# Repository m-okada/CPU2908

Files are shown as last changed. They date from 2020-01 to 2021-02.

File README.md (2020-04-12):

CPU2908
====

Open source home brew 8-bit CPU.
----
CPU2908は、74HCシリーズ標準ロジックとROMで作る8ビットCPUです。

FPGAにもインプリメントしてあります。
ターゲットデバイスはLattice MachXO2-1200HC、又は2000HCです。
FPGA版は既にプロトタイプ基版まで出来ているので、不具合を修正してリリース版を作ります。

アーキテクチャ
----
- 8ビットCPU、リトルエンディアン
- 4つの汎用8ビットレジスタ。2つまとめて16ビットレジスタとして使う命令があります
- 4つの16ビットアドレスレジスタ。うち1つはスタックポインタ、1つはプログラムカウンタです
- 命令は全て8ビット長で、後ろにイミディエイト値が1～2バイトつく場合があります
- μCode方式です
- ロード／ストア命令、データ移動命令、算術／論理演算、条件ジャンプ、CALL／RET命令などがあります
- CALL/JUMP命令は8/16ビットオフセット(プログラムカウンタ相対)です

レジスタ構成
----

### 8ビット汎用レジスタR0～R3。

R1とR0は合わせてW0、R3とR2は合わせてW1と表現します。アドレスレジスタとのデータ転送、INC/DEC命令で16ビットレジスタとして使えます。

### 16ビットアドレスレジスタA0、A1、CP、SP。
アドレスレジスタA0、A1はロード/ストア命令でアドレスを指定するのに使います。
また、汎用16ビットレジスタとのデータ転送、交換などの命令もあります。

SPはスタックポインタです。PUSH/POP命令のアドレスはSPが暗黙で指定されます。

CPはコードポインタです。プログラムカウンタ（PC）とかインストラクションポインタ（IP）などの呼び方がありますが、SPがスタックポインタなので、CPがコードポインタです。

μCode方式
----
CPU2908は、主に部品数を減らすためとコード密度を高くするために、μCode（厳密にはコントロールストアと呼ばれる方式）で命令をデコードしています。

回路について
====

回路は
- Logisimのドキュメント CPU2908/Document/CPU2908C3.circ
- KiCadの回路図 CPU2908/blob/master/Schematics/74HC/RevC3/CPU2908C3.sch

の2つで、どちらも同じ回路です。
最初にLogisim用の回路を作り、動作するμCODEを作りました。これでシミュレーションをしながら動作の確認をして、それからKiCadの回路図を起こしました。
MachXO2用のファイルもこの回路図を元に、回路図入力で作ってあります。

詳細は　CPU2908/Document/CPU2908C.ods　にあります。
インストラクションセット、μROM、ピンアウトなど解説してあります。

その他
====
開発の進捗など含めて計算機について色々呟いています。
https://twitter.com/MyCPU8

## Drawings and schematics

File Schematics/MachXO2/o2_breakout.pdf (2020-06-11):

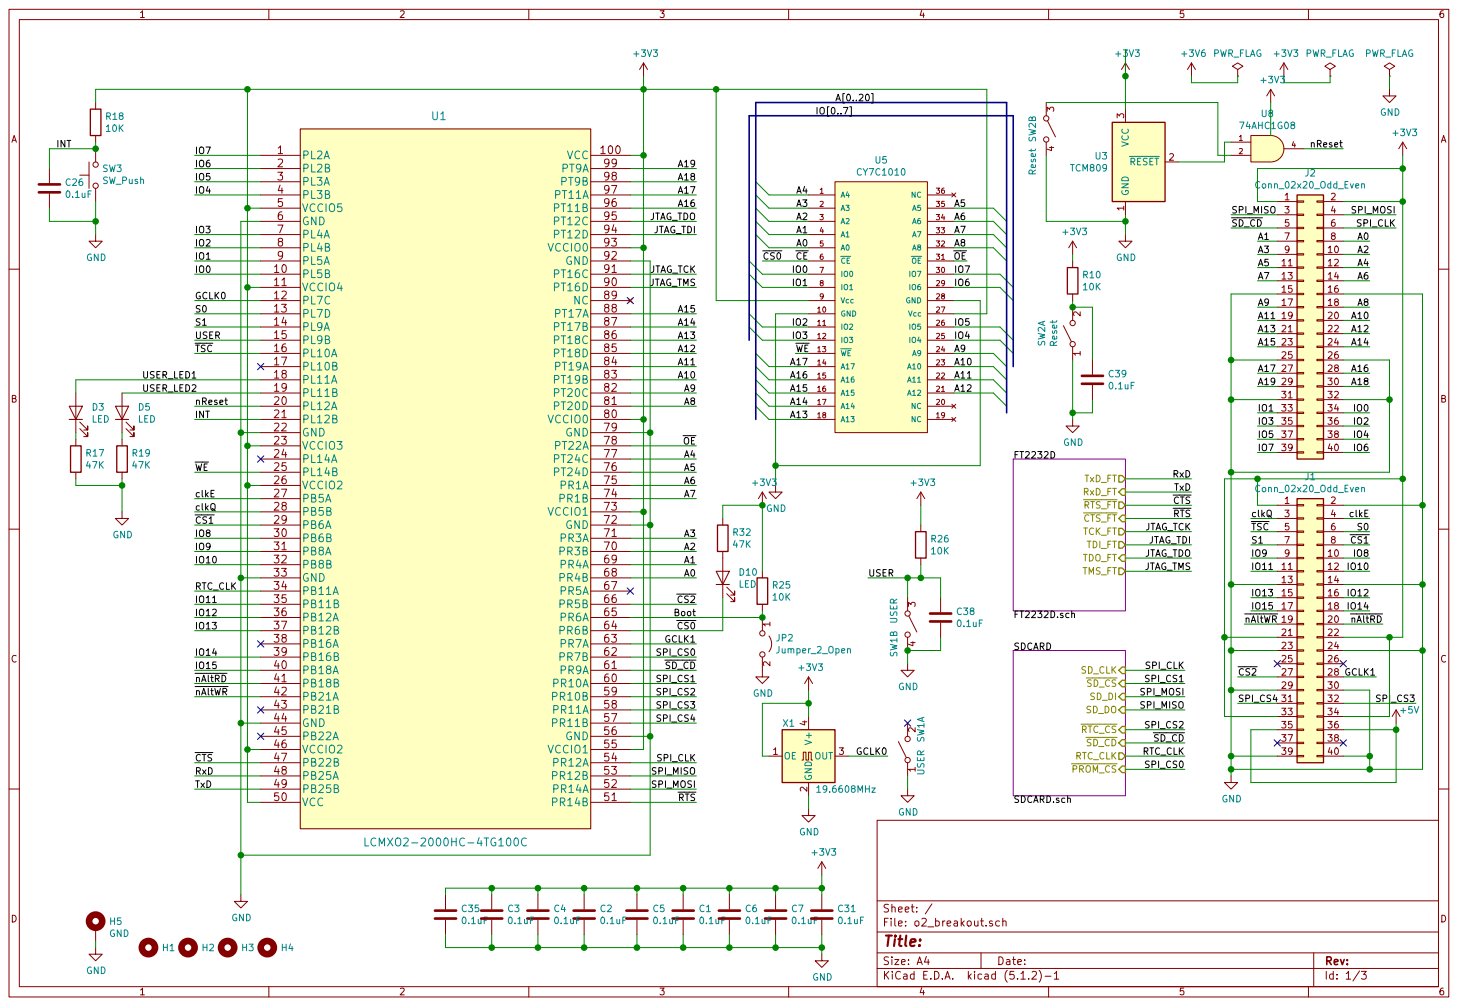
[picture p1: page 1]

17 | SPI_CLK RxD 18

35 | 36
37 39 | 38 40

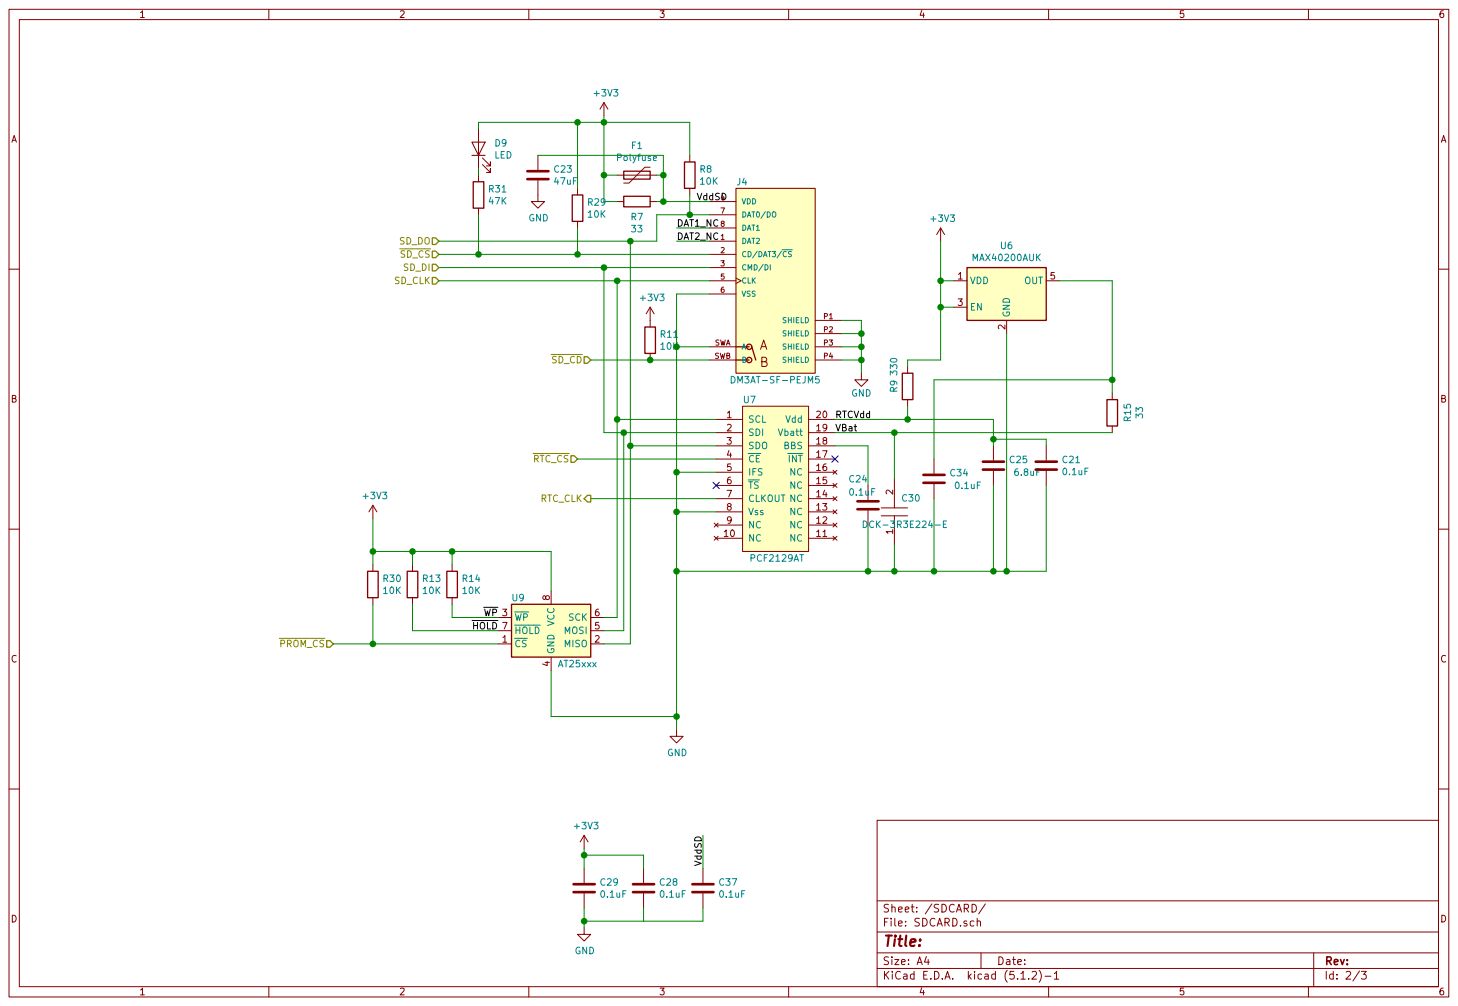
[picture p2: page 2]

Id: 2/3 Title: File: SDCARD.sch Sheet: /SDCARD/ AB

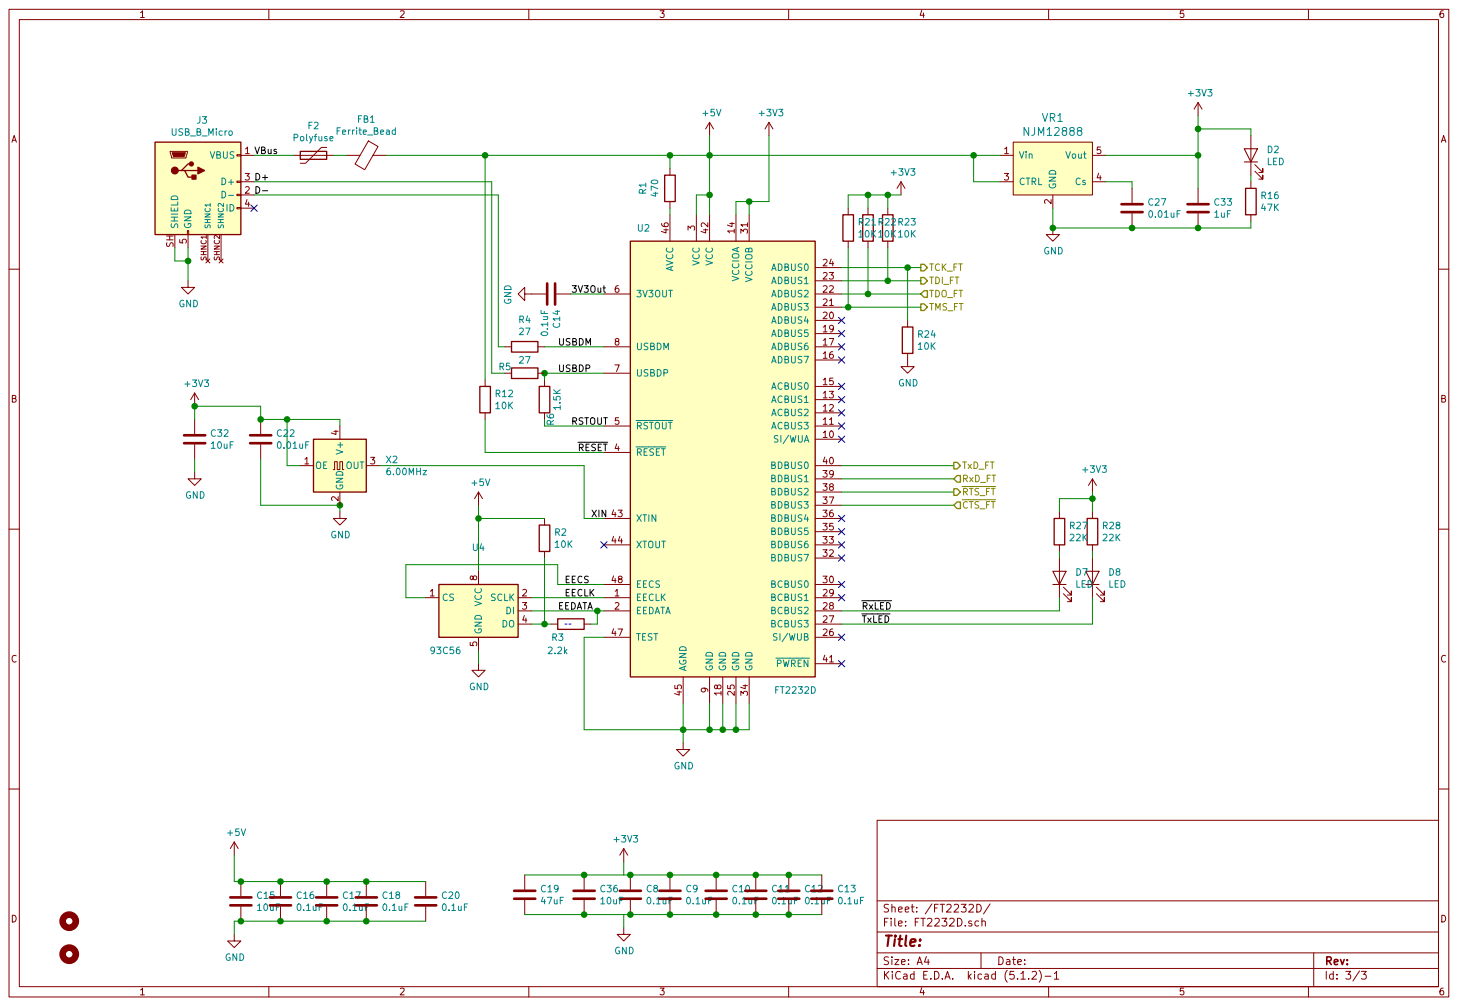
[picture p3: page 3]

2 CTRL 3 Cs 4 Vout 5 VR1 NJM12888 GND GND

3 BCBUS0 30 VCCIOB 31 BDBUS7 32 BDBUS6 33 GND 34 BDBUS5 35 BDBUS4 36 BDBUS3 37 BDBUS2 38 BDBUS1 39 RESET 4 BDBUS0 40 PWREN 41 VCC 42 XTIN 43 XTOUT 44 AGND 45 AVCC 46 TEST 47 EECS 48 RSTOUT 5

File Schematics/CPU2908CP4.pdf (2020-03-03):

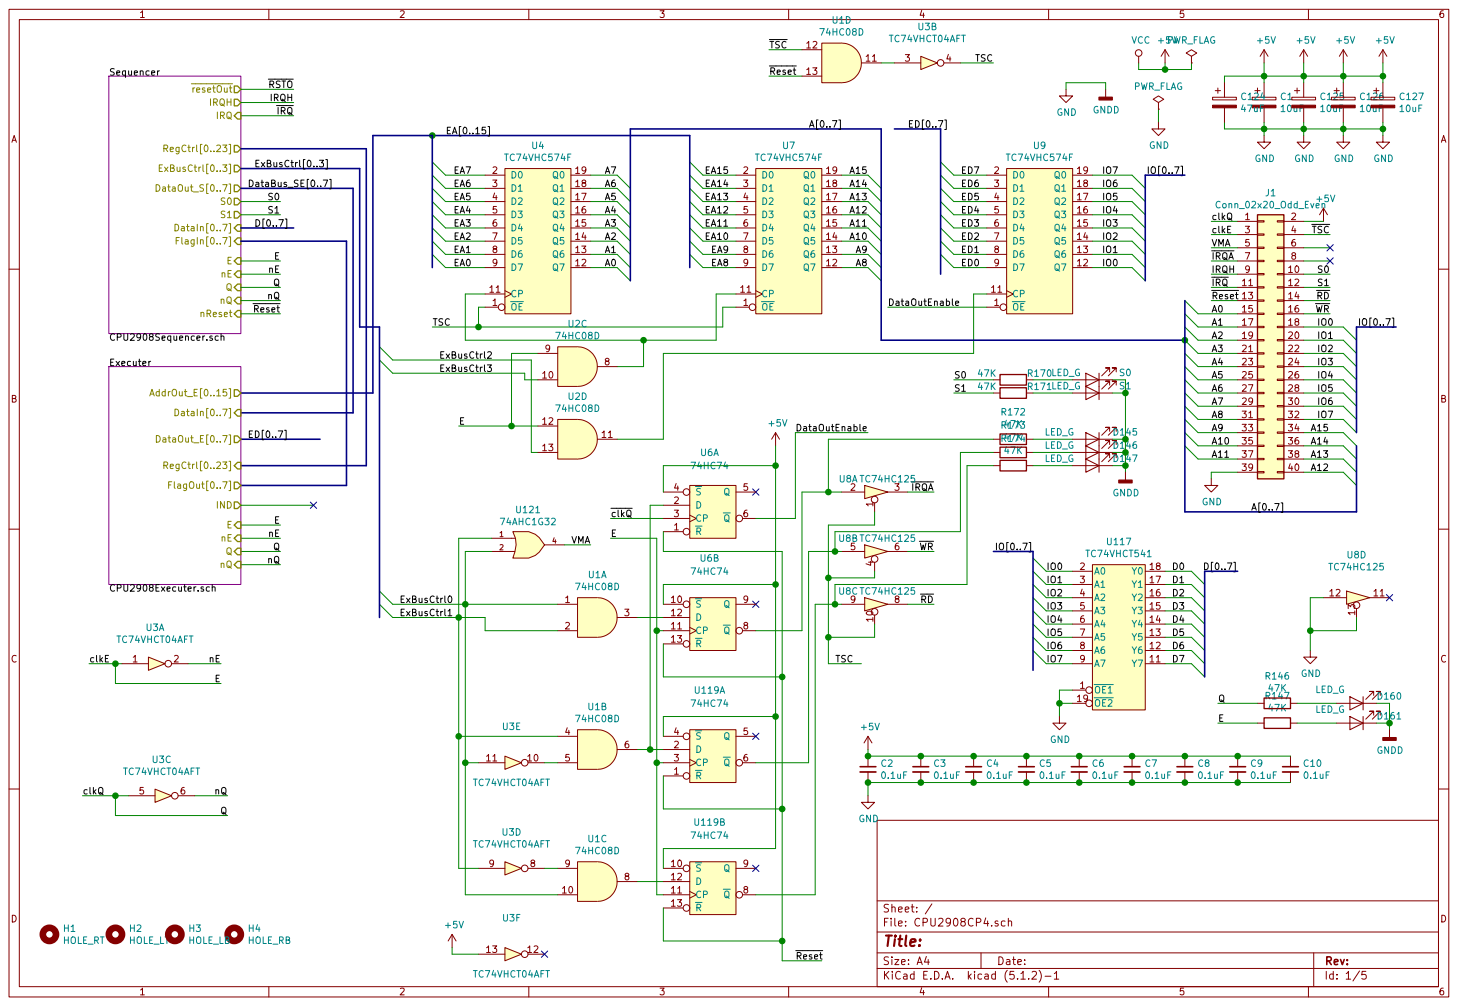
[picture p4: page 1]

Id: 1/5 Title: File: CPU2908CP4.sch Sheet: /

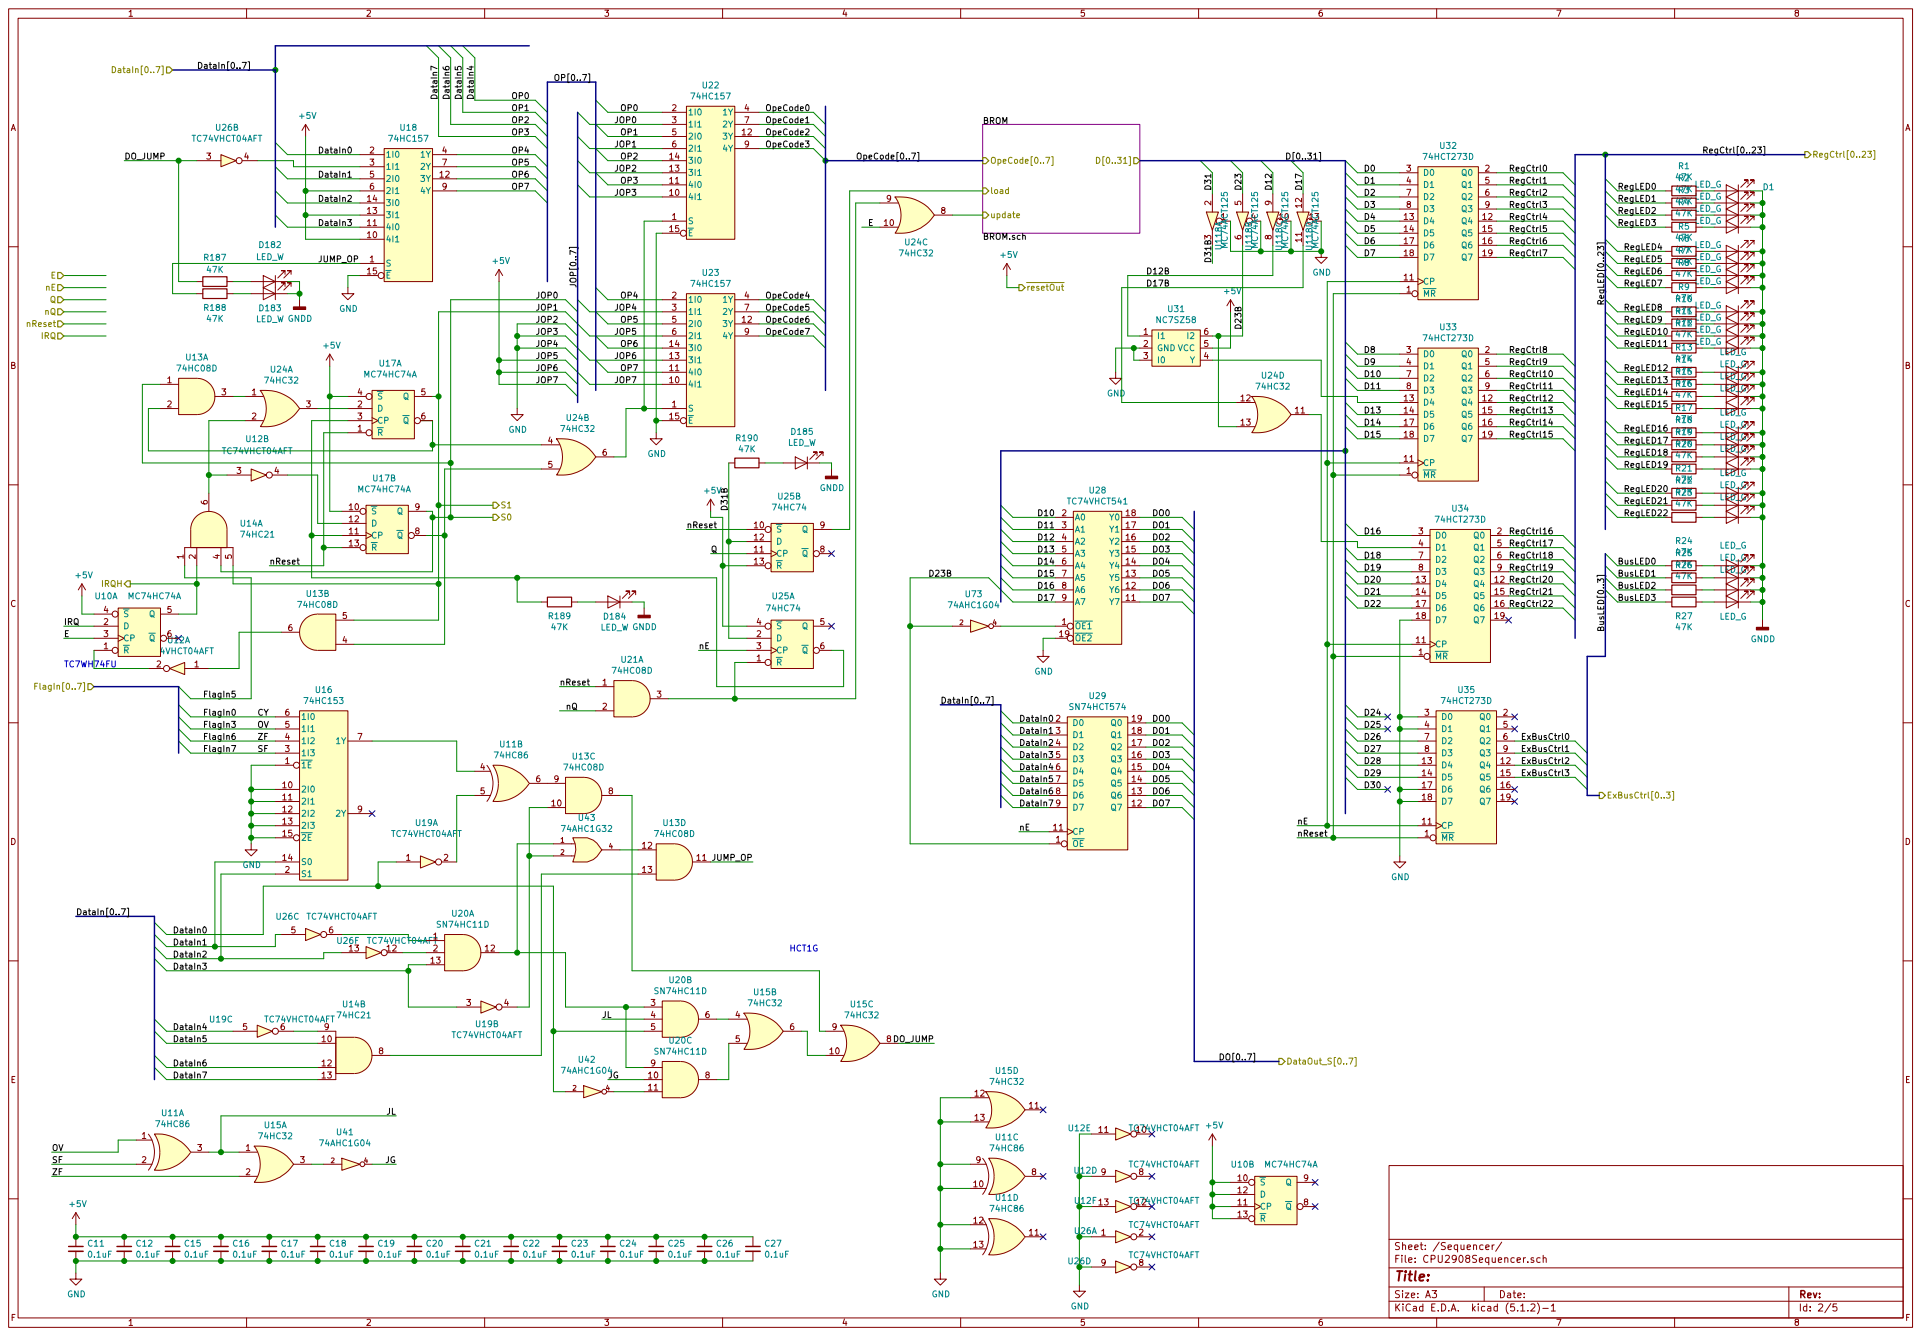
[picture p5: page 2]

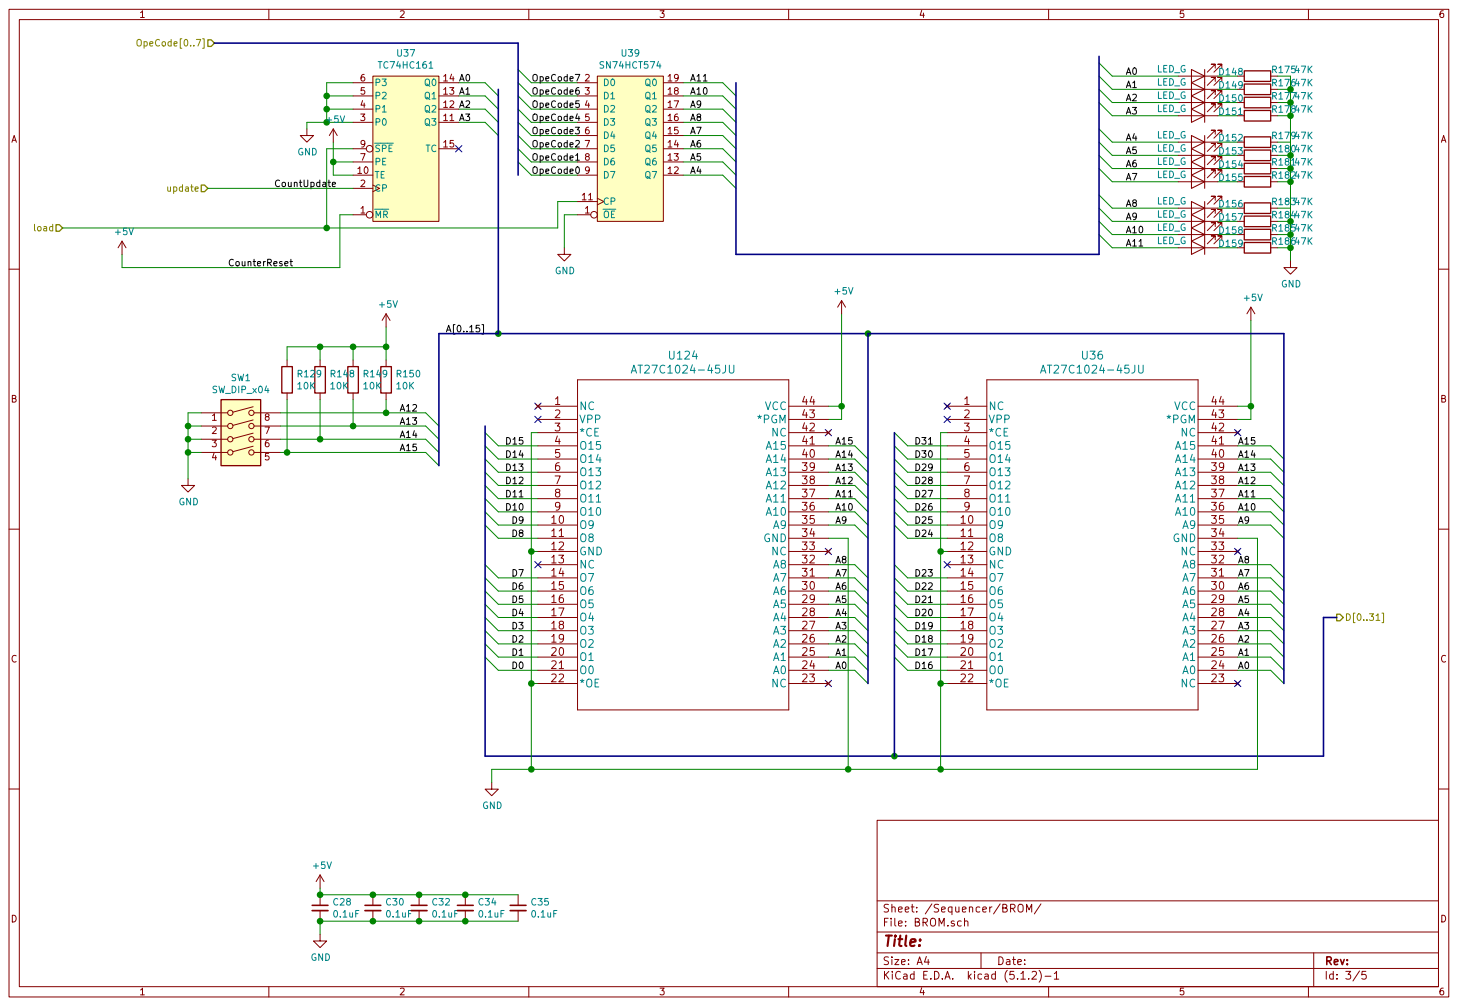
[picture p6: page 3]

Id: 3/5 Title: File: BROM.sch Sheet: /Sequencer/BROM/

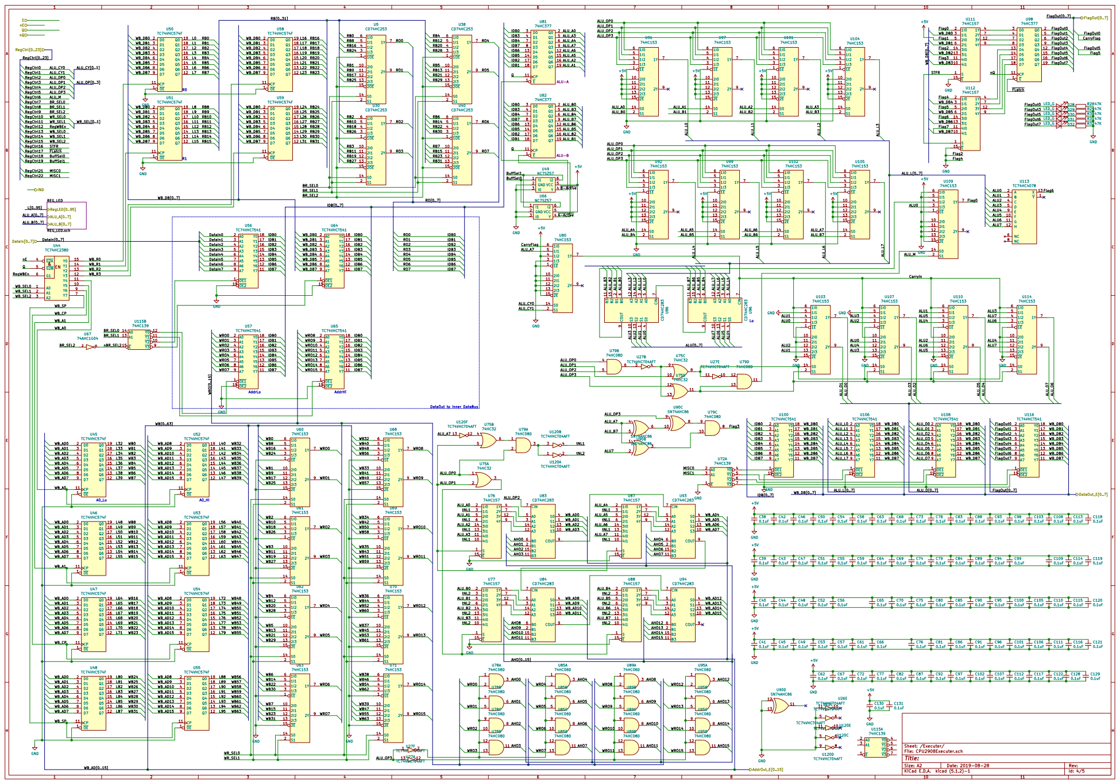
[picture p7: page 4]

TC74VHCT04AFT DataOut to Inner DataBus

Id: 4/5 Title: File: CPU2908Executer.sch Sheet: /Executer/

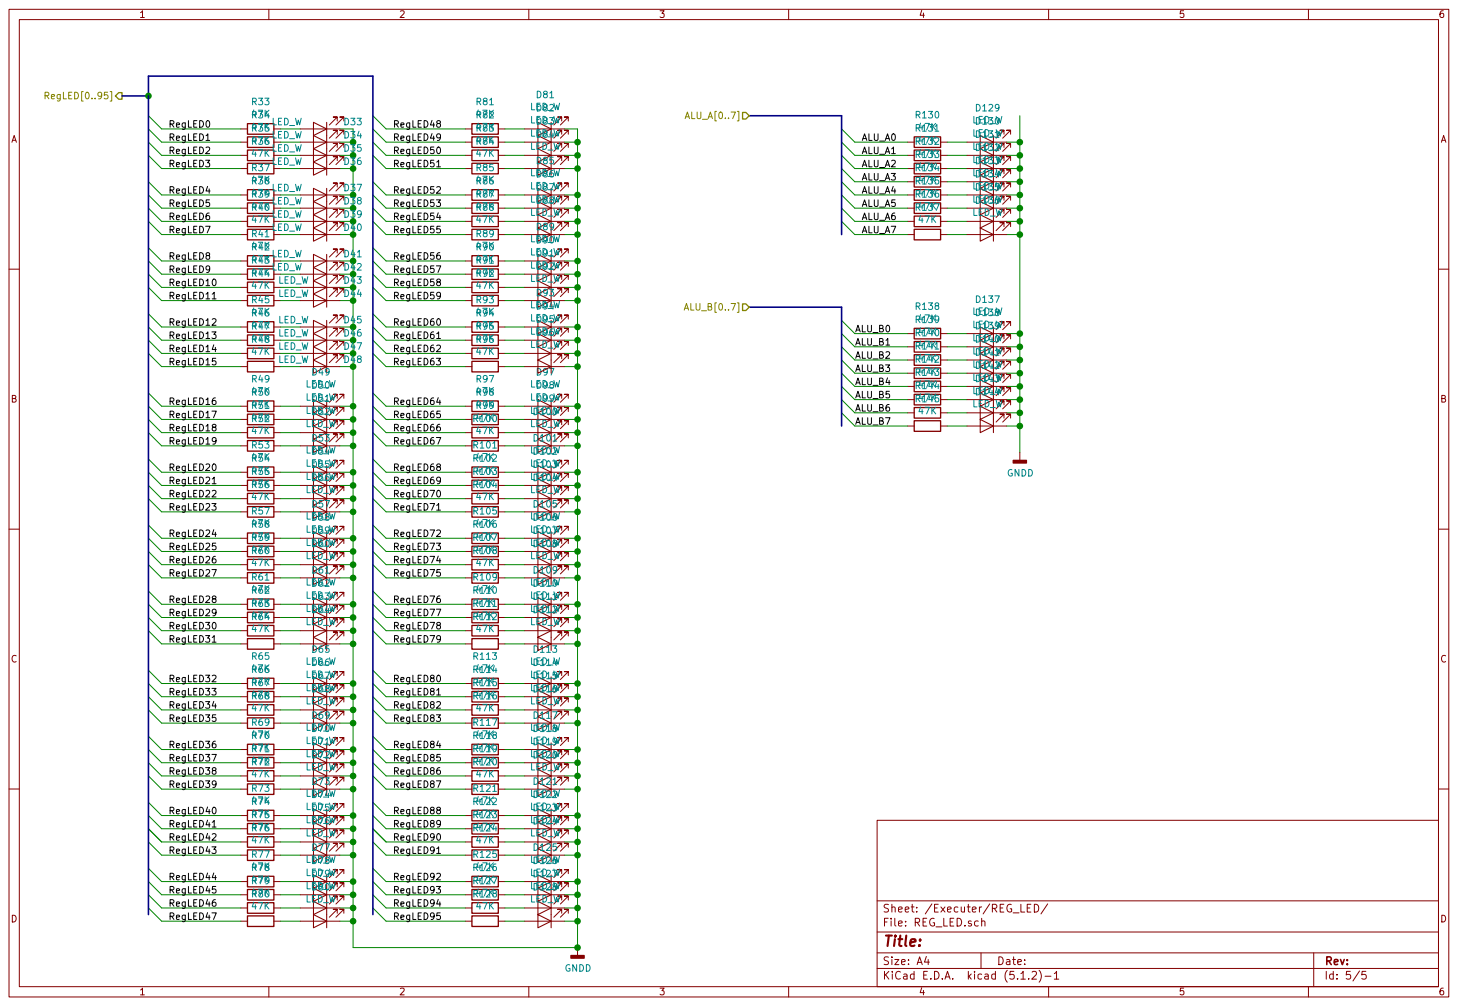
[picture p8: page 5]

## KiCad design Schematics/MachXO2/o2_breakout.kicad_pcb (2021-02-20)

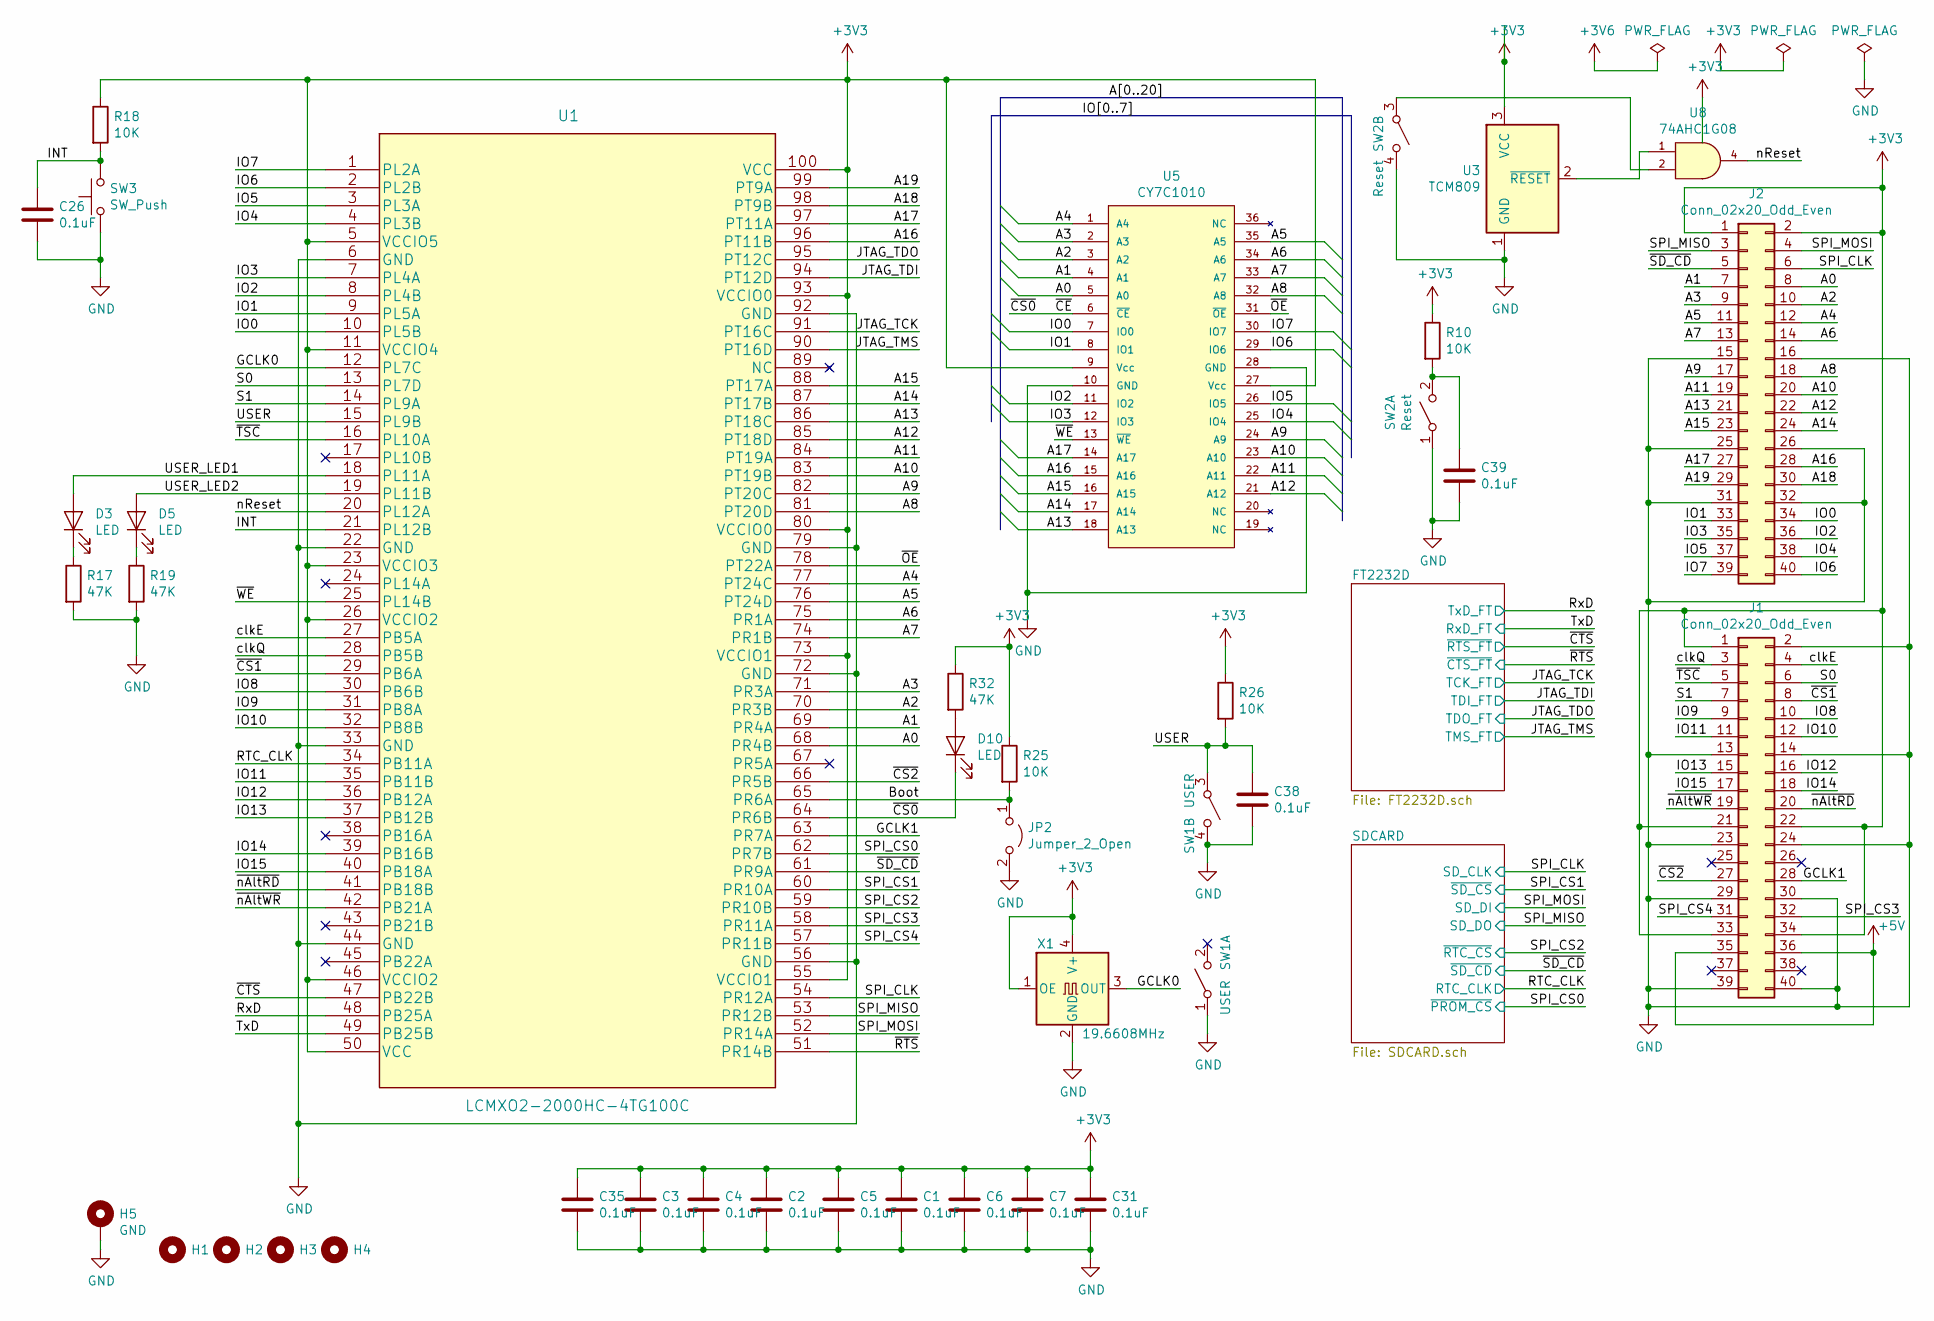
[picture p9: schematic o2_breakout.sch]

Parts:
C1, C2, C3, C4, C5, C6, C7, C26, C31, C35, C38, C39: 0.1uF; C_0402
D3, D5, D10: LED; C_0603
H1, H2, H3, H4: MountingHole; MountingHole_3.2mm_M3
H5: GND; Pin_Header_Straight_1x01_Pitch1.00mm
J1, J2: Conn_02x20_Odd_Even; Pin_Header_Straight_2x20_Pitch2.54mm
JP2: Jumper_2_Open; WireConnection_1.00mmDrill
R10, R18, R25, R26: 10K; C_0402
R17, R19, R32: 47K; C_0402
SW1: USER; SW_PUSH_6mm
SW2: Reset; SW_PUSH_6mm
SW3: SW_Push; SMD-2_3.2x1.5mm
U1: LCMXO2-2000HC-4TG100C; TQFP-100_14x14mm
U3: TCM809; SOT-23-3
U5: CY7C1010; SOJ-36_10.16x23.49mm_P1.27mm
U8: 74AHC1G08; SOT-353_SC-70-5
X1: 19.6608MHz; Oscillator_SMD_EuroQuartz_XO53-4pin_5.0x3.2mm_HandSoldering

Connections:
+3V3: C1.1, C2.1, C3.1, C4.1, C5.1, C6.1, C7.1, C31.1, C35.1, J1.1, J1.21, J1.22, J1.33, J1.34, J2.1, J2.2, R10.1, R18.1, R25.1, R26.1, R32.1, U1.5 (VCCIO5), U1.11 (VCCIO4), U1.23 (VCCIO3), U1.26 (VCCIO2), U1.46 (VCCIO2), U1.50 (VCC), U1.55 (VCCIO1), U1.73 (VCCIO1), U1.80 (VCCIO0), U1.93 (VCCIO0), U1.100 (VCC), U3.3 (VCC), U5.9 (Vcc), U5.27 (Vcc), U8.5 (VCC), X1.1 (OE), X1.4 (V+); also elsewhere on the board
+5V: J1.35, J1.36; also elsewhere on the board
/A0: J2.8, U1.68 (PR4B), U5.5 (A0)
/A1: J2.7, U1.69 (PR4A), U5.4 (A1)
/A2: J2.10, U1.70 (PR3B), U5.3 (A2)
/A3: J2.9, U1.71 (PR3A), U5.2 (A3)
/A4: J2.12, U1.77 (PT24C), U5.1 (A4)
/A5: J2.11, U1.76 (PT24D), U5.35 (A5)
/A6: J2.14, U1.75 (PR1A), U5.34 (A6)
/A7: J2.13, U1.74 (PR1B), U5.33 (A7)
/A8: J2.18, U1.81 (PT20D), U5.32 (A8)
/A9: J2.17, U1.82 (PT20C), U5.24 (A9)
/A10: J2.20, U1.83 (PT19B), U5.23 (A10)
/A11: J2.19, U1.84 (PT19A), U5.22 (A11)
/A12: J2.22, U1.85 (PT18D), U5.21 (A12)
/A13: J2.21, U1.86 (PT18C), U5.18 (A13)
/A14: J2.24, U1.87 (PT17B), U5.17 (A14)
/A15: J2.23, U1.88 (PT17A), U5.16 (A15)
/A16: J2.28, U1.96 (PT11B), U5.15 (A16)
/A17: J2.27, U1.97 (PT11A), U5.14 (A17)
/A18: J2.30, U1.98 (PT9B)
/A19: J2.29, U1.99 (PT9A)
/Boot: JP2.1 (A), R25.2, U1.65 (PR6A)
/GCLK0: U1.12 (PL7C), X1.3 (OUT)
/GCLK1: J1.28, U1.63 (PR7A)
/INT: C26.1, R18.2, SW3.2, U1.21 (PL12B)
/IO0: J2.34, U1.10 (PL5B), U5.7 (IO0)
/IO1: J2.33, U1.9 (PL5A), U5.8 (IO1)
/IO2: J2.36, U1.8 (PL4B), U5.11 (IO2)
/IO3: J2.35, U1.7 (PL4A), U5.12 (IO3)
/IO4: J2.38, U1.4 (PL3B), U5.25 (IO4)
/IO5: J2.37, U1.3 (PL3A), U5.26 (IO5)
/IO6: J2.40, U1.2 (PL2B), U5.29 (IO6)
/IO7: J2.39, U1.1 (PL2A), U5.30 (IO7)
/IO8: J1.10, U1.30 (PB6B)
/IO9: J1.9, U1.31 (PB8A)
/IO10: J1.12, U1.32 (PB8B)
/IO11: J1.11, U1.35 (PB11B)
/IO12: J1.16, U1.36 (PB12A)
/IO13: J1.15, U1.37 (PB12B)
/IO14: J1.18, U1.39 (PB16B)
/IO15: J1.17, U1.40 (PB18A)
/JTAG_TCK: U1.91 (PT16C); also elsewhere on the board
/JTAG_TDI: U1.94 (PT12D); also elsewhere on the board
/JTAG_TDO: U1.95 (PT12C); also elsewhere on the board
/JTAG_TMS: U1.90 (PT16D); also elsewhere on the board
/RTC_CLK: U1.34 (PB11A); also elsewhere on the board
/RxD: U1.48 (PB25A); also elsewhere on the board
/S0: J1.6, U1.13 (PL7D)
/S1: J1.7, U1.14 (PL9A)
/SPI_CLK: J2.6, U1.54 (PR12A); also elsewhere on the board
/SPI_CS0: U1.62 (PR7B); also elsewhere on the board
/SPI_CS1: U1.60 (PR10A); also elsewhere on the board
/SPI_CS2: U1.59 (PR10B); also elsewhere on the board
/SPI_CS3: J1.32, U1.58 (PR11A)
/SPI_CS4: J1.31, U1.57 (PR11B)
/SPI_MISO: J2.3, U1.53 (PR12B); also elsewhere on the board
/SPI_MOSI: J2.4, U1.52 (PR14A); also elsewhere on the board
/TxD: U1.49 (PB25B); also elsewhere on the board
/USER: C38.1, R26.2, SW1.3 (A), U1.15 (PL9B)
/USER_LED1: D3.2 (A), U1.18 (PL11A)
/USER_LED2: D5.2 (A), U1.19 (PL11B)
/clkE: J1.4, U1.27 (PB5A)
/clkQ: J1.3, U1.28 (PB5B)
/nReset: U1.20 (PL12A), U8.4
/~CE: D10.1 (K), U1.64 (PR6B), U5.6 (~CE)
/~CS1: J1.8, U1.29 (PB6A)
/~CS2: J1.27, U1.66 (PR5B)
/~CTS: U1.47 (PB22B); also elsewhere on the board
/~OE: U1.78 (PT22A), U5.31 (~OE)
/~RTS: U1.51 (PR14B); also elsewhere on the board
/~SD_CD: J2.5, U1.61 (PR9A); also elsewhere on the board
/~TSC: J1.5, U1.16 (PL10A)
/~WE: U1.25 (PL14B), U5.13 (~WE)
/~nAltRD: J1.20, U1.41 (PB18B)
/~nAltWR: J1.19, U1.42 (PB21A)
GND: C1.2, C2.2, C3.2, C4.2, C5.2, C6.2, C7.2, C26.2, C31.2, C35.2, C38.2, C39.2, H5.1, J1.2, J1.13, J1.14, J1.23, J1.24, J1.29, J1.30, J1.39, J1.40, J2.15, J2.16, J2.25, J2.26, J2.31, J2.32, JP2.2 (B), R17.2, R19.2, SW1.1 (A), SW1.4 (B), SW2.1 (A), SW2.4 (B), SW3.1, U1.6 (GND), U1.22 (GND), U1.33 (GND), U1.44 (GND), U1.56 (GND), U1.72 (GND), U1.79 (GND), U1.92 (GND), U3.1 (GND), U5.10 (GND), U5.28 (GND), U8.3 (GND), X1.2 (GND); also elsewhere on the board
unnamed: C39.1, R10.2, SW2.2 (B)
unnamed: D3.1 (K), R17.1
unnamed: D5.1 (K), R19.1
unnamed: D10.2 (A), R32.2
unnamed: SW2.3 (A), U8.2
unnamed: U3.2 (~RESET~), U8.1

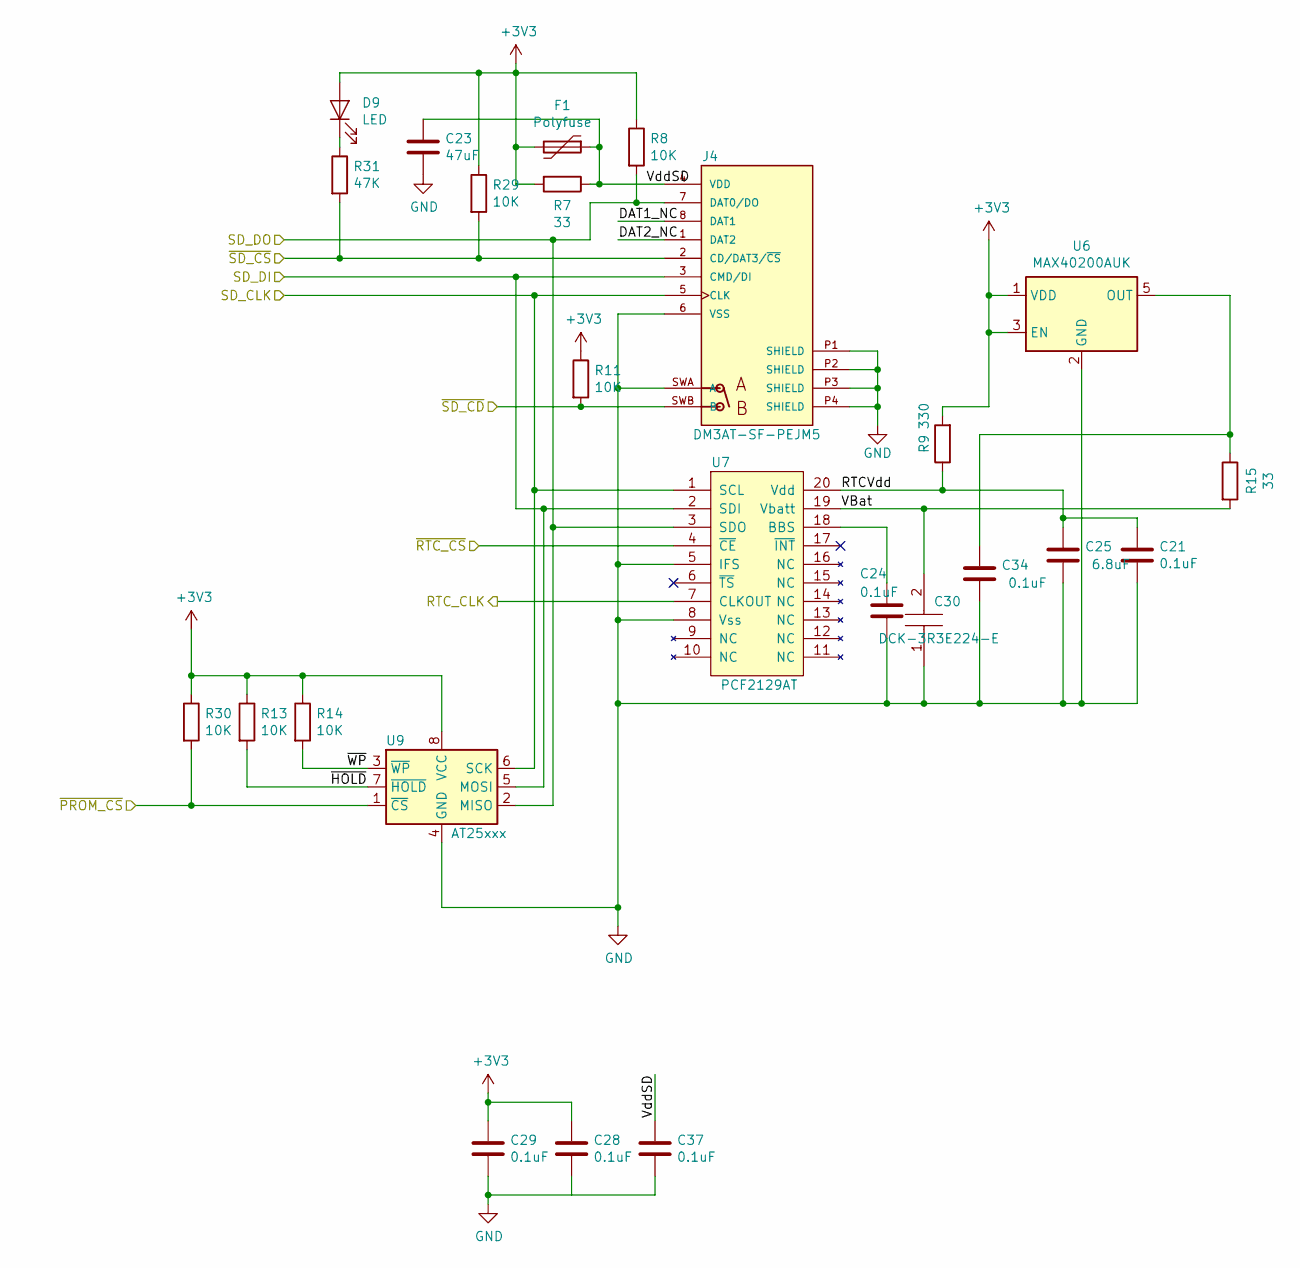
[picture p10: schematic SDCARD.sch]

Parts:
C21, C24, C28, C29, C34, C37: 0.1uF; C_0402
C23: 47uF; C_1210
C25: 6.8uF; C_0805
C30: DCK-3R3E224-E; Manufacturer_Part_Number DCK-3R3E224-E
D9: LED; C_0603
F1: Polyfuse; C_0805
J4: DM3AT-SF-PEJM5; HRS_DM3AT-SF-PEJM5
R7: 33; C_0805
R8, R11, R13, R14, R29, R30: 10K; C_0402
R9: 330; C_0603
R15: 33; C_0603
R31: 47K; C_0402
U6: MAX40200AUK; SOT-23-5
U7: PCF2129AT; SOIC-20W_7.5x12.8mm_Pitch1.27mm
U9: AT25xxx; SOIC-8_3.9x4.9mm_Pitch1.27mm

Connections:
+3V3: C28.1, C29.1, D9.2 (A), F1.2, R7.2, R8.1, R9.2, R11.1, R13.1, R14.1, R29.1, R30.1, U6.1 (VDD), U6.3 (EN), U9.8 (VCC); also elsewhere on the board
/RTC_CLK: U7.7 (CLKOUT); also elsewhere on the board
/SDCARD/DAT1_NC: J4.8 (DAT1)
/SDCARD/DAT2_NC: J4.1 (DAT2)
/SDCARD/RTCVdd: C21.1, C25.1, R9.1, U7.20 (Vdd)
/SDCARD/VBat: C30.2, R15.2, U7.19 (Vbatt)
/SDCARD/VddSD: C23.1, C37.1, F1.1, J4.4 (VDD), R7.1
/SDCARD/~HOLD: R13.2, U9.7 (~HOLD)
/SDCARD/~WP: R14.2, U9.3 (~WP)
/SPI_CLK: J4.5 (CLK), U7.1 (SCL), U9.6 (SCK); also elsewhere on the board
/SPI_CS0: R30.2, U9.1 (~CS); also elsewhere on the board
/SPI_CS1: J4.2 (CD/DAT3/~CS), R29.2, R31.2; also elsewhere on the board
/SPI_CS2: U7.4 (~CE); also elsewhere on the board
/SPI_MISO: J4.7 (DAT0/DO), R8.2, U7.3 (SDO), U9.2 (MISO); also elsewhere on the board
/SPI_MOSI: J4.3 (CMD/DI), U7.2 (SDI), U9.5 (MOSI); also elsewhere on the board
/~SD_CD: J4.SWB (B), R11.2; also elsewhere on the board
GND: C21.2, C23.2, C24.2, C25.2, C28.2, C29.2, C30.1, C34.2, C37.2, J4.6 (VSS), J4.P1 (SHIELD), J4.P2 (SHIELD), J4.P3 (SHIELD), J4.P4 (SHIELD), J4.SWA (A), U6.2 (GND), U7.5 (IFS), U7.8 (Vss), U9.4 (GND); also elsewhere on the board
unnamed: C24.1, U7.18 (BBS)
unnamed: C34.1, R15.1, U6.5 (OUT)
unnamed: D9.1 (K), R31.1

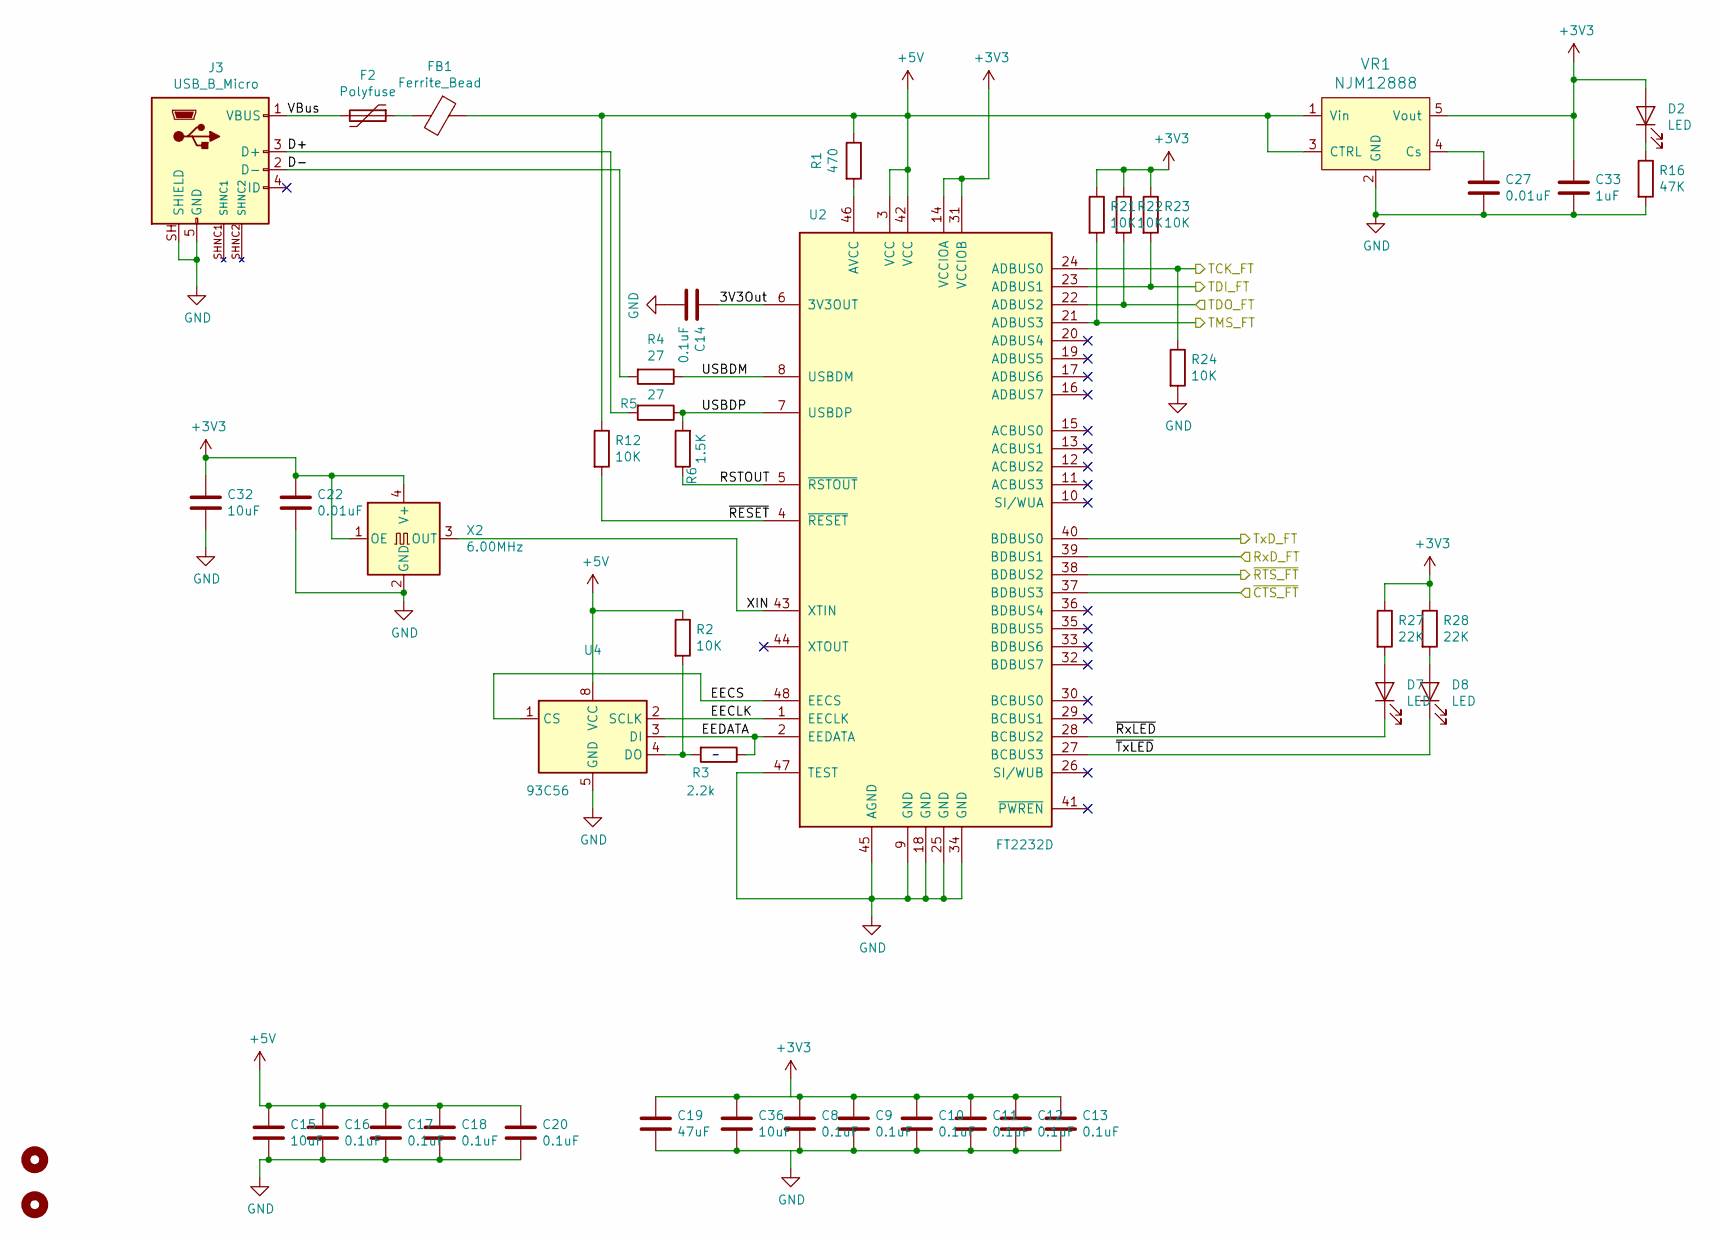
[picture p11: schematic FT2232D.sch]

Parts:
C8, C9, C10, C11, C12, C13, C14, C16, C17, C18, C20: 0.1uF; C_0402
C15, C36: 10uF; C_0603
C19: 47uF; C_0805_HandSoldering
C22: 0.01uF; C_0402
C27: 0.01uF; C_0603
C32: 10uF; C_0805_HandSoldering
C33: 1uF; C_0603
D2: LED; C_0603
D7, D8: LED; C_0402
F2: Polyfuse; C_0805
FB1: Ferrite_Bead; C_0805
H6, H7: MountingHole; MountingHole_1.2mm
J3: USB_B_Micro; HRS_ZX62R-B-5P
R1: 470; C_0603
R2: 10K; C_0603
R3: 2.2k; C_0603
R4, R5: 27; C_0603
R6: 1.5K; C_0603
R12, R21, R22, R23, R24: 10K; C_0402
R16: 47K; C_0603
R27, R28: 22K; C_0402
U2: FT2232D; TQFP-48_7x7mm
U4: 93C56; SOIC-8_3.9x4.9mm_Pitch1.27mm
VR1: NJM12888; SOT-23-5
X2: 6.00MHz; Oscillator_SMD_SeikoEpson_SG8002LB-4pin_5.0x3.2mm_HandSolde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

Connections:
+3V3: C8.1, C9.1, C10.1, C11.1, C12.1, C13.1, C19.1, C22.1, C32.1, C33.1, C36.1, D2.2 (A), R21.1, R22.1, R23.1, R27.1, R28.1, U2.14 (VCCIOA), U2.31 (VCCIOB), VR1.5 (Vout), X2.1 (OE), X2.4 (V+); also elsewhere on the board
+5V: C15.1, C16.1, C17.1, C18.1, C20.1, FB1.1, R1.1, R2.1, R12.1, U2.3 (VCC), U2.42 (VCC), U4.8 (VCC), VR1.1 (Vin), VR1.3 (CTRL); also elsewhere on the board
/FT2232D/3V3Out: C14.1, U2.6 (3V3OUT)
/FT2232D/D+: J3.3 (D+), R5.2
/FT2232D/D-: J3.2 (D-), R4.2
/FT2232D/EECLK: U2.1 (EECLK), U4.2 (SCLK)
/FT2232D/EECS: U2.48 (EECS), U4.1 (CS)
/FT2232D/EEDATA: R3.1, U2.2 (EEDATA), U4.3 (DI)
/FT2232D/RSTOUT: R6.1, U2.5 (~RSTOUT)
/FT2232D/USBDM: R4.1, U2.8 (USBDM)
/FT2232D/USBDP: R5.1, R6.2, U2.7 (USBDP)
/FT2232D/VBus: F2.2, J3.1 (VBUS)
/FT2232D/XIN: U2.43 (XTIN), X2.3 (OUT)
/FT2232D/~RESET: R12.2, U2.4 (~RESET)
/FT2232D/~RxLED: D7.1 (K), U2.28 (BCBUS2)
/FT2232D/~TxLED: D8.1 (K), U2.27 (BCBUS3)
/JTAG_TCK: R24.1, U2.24 (ADBUS0); also elsewhere on the board
/JTAG_TDI: R23.2, U2.23 (ADBUS1); also elsewhere on the board
/JTAG_TDO: R22.2, U2.22 (ADBUS2); also elsewhere on the board
/JTAG_TMS: R21.2, U2.21 (ADBUS3); also elsewhere on the board
/RxD: U2.40 (BDBUS0); also elsewhere on the board
/TxD: U2.39 (BDBUS1); also elsewhere on the board
/~CTS: U2.38 (BDBUS2); also elsewhere on the board
/~RTS: U2.37 (BDBUS3); also elsewhere on the board
GND: C8.2, C9.2, C10.2, C11.2, C12.2, C13.2, C14.2, C15.2, C16.2, C17.2, C18.2, C19.2, C20.2, C22.2, C27.2, C32.2, C33.2, C36.2, J3.5 (GND), J3.SH (SHIELD), R16.2, R24.2, U2.9 (GND), U2.18 (GND), U2.25 (GND), U2.34 (GND), U2.45 (AGND), U2.47 (TEST), U4.5 (GND), VR1.2 (GND), X2.2 (GND); also elsewhere on the board
unnamed: C27.1, VR1.4 (Cs)
unnamed: D2.1 (K), R16.1
unnamed: D7.2 (A), R27.2
unnamed: D8.2 (A), R28.2
unnamed: F2.1, FB1.2
unnamed: R1.2, U2.46 (AVCC)
unnamed: R2.2, R3.2, U4.4 (DO)

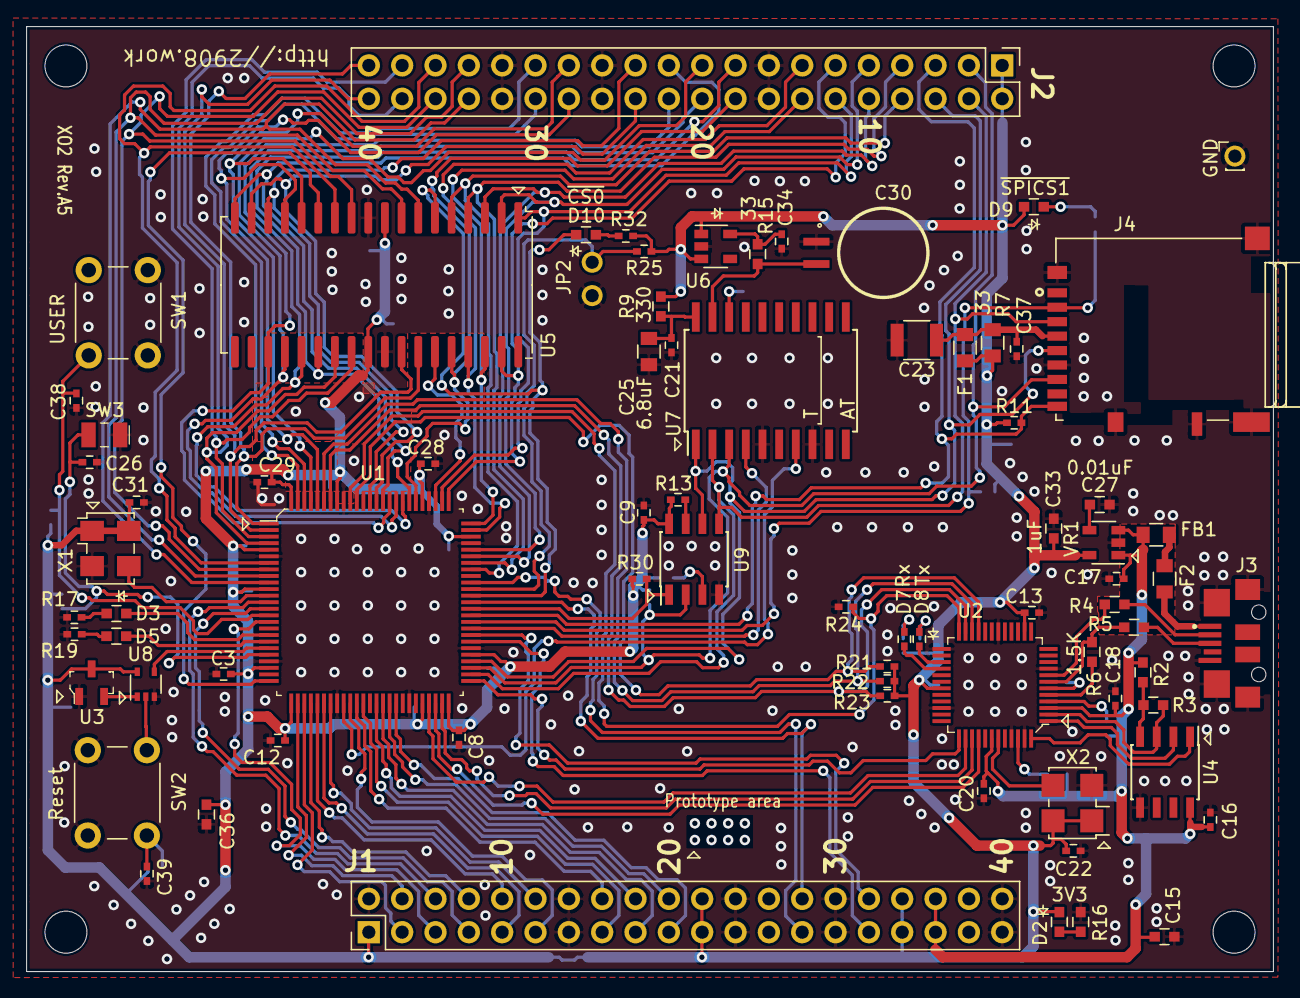
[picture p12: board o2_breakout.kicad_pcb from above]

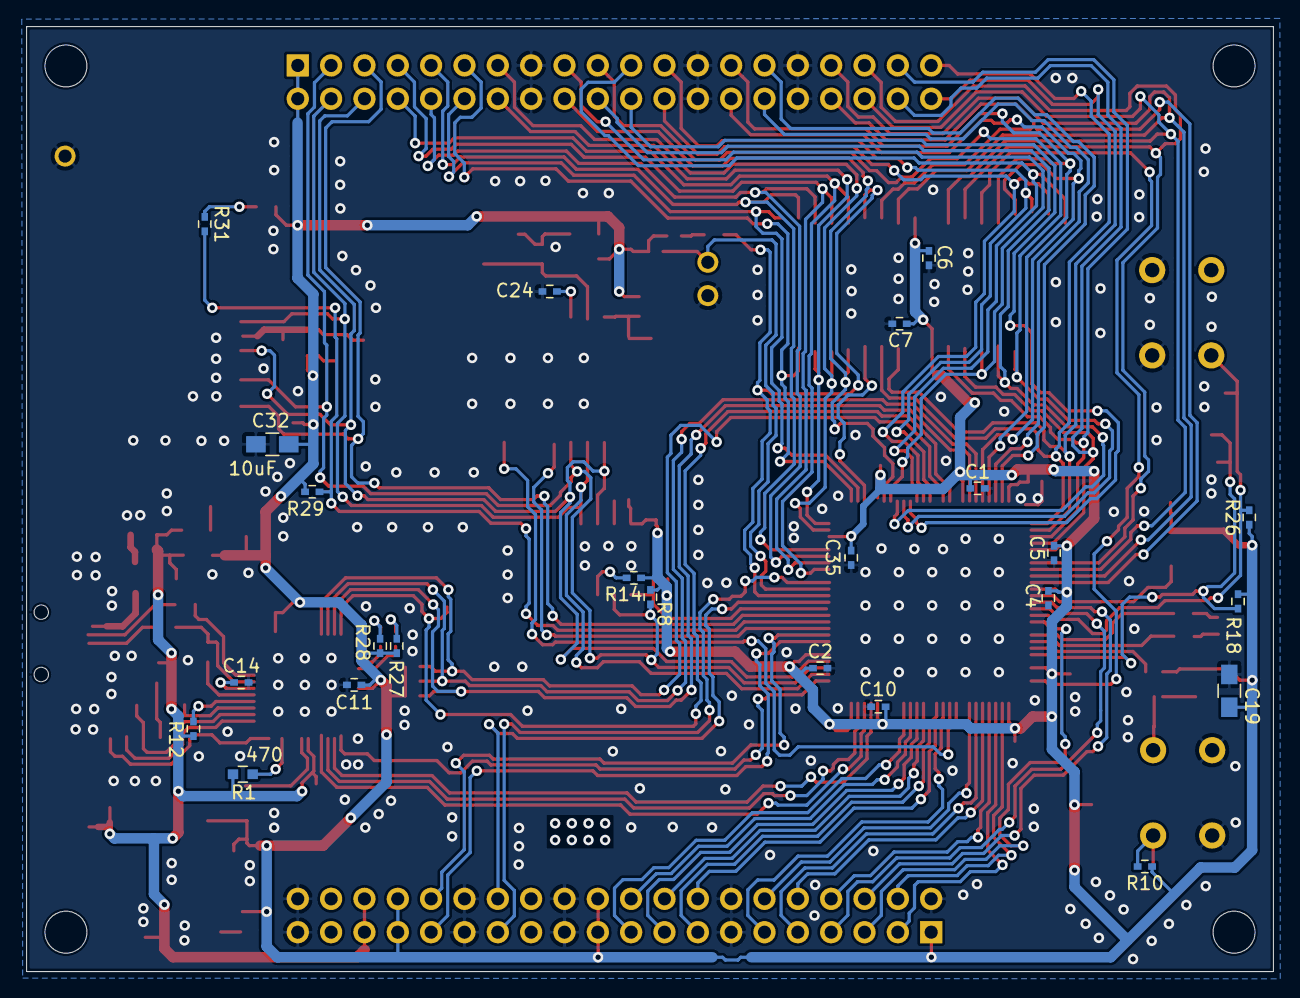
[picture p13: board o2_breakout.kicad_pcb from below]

Board: 2 copper layers, 95.0 x 72.0 mm, 107 parts (24 on the bottom side), 112 nets.

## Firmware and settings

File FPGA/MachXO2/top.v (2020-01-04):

module top(
	inout wire [7:0] dataBus,
	output wire [3:0] nCS,		// chip select 0:ROM 1:RAM 2..:I/O
	input wire clk,
	input wire gclk1,

	input wire nReset,
	input wire nIRQ,
	input wire nTSC,
	
	input wire bootMode,
	
	output wire [19:0] addrOut,
	output wire clkQ,
	output wire clkE,

	output wire nRD,nAltRD,
	output wire nWR,nAltWR,
	output wire nIRQA,
	output wire IRQH,
	
	output wire [1:0]S,
	

	output wire SPI_CLK,
	output wire SPI_MISO,
	output wire SPI_MOSI,
	output wire [5:0]SPI_CS,

	output wire TxD,
	input wire RxD,
	output wire nRTS,
	input wire nCTS,
	output wire SerialClock,

	input wire [3:0]monitor_sel,
	output wire [7:0]UM
);
//wire [3:0]monitor_sel ;
wire [127:0]sig ;


wire [7:0]ExDataIn ;
wire [7:0]ExDataOut ;

wire [15:0]addr ;
wire [3:0] addrHi ;

//wire nwr_temp ;

assign addrOut[15:0] = addr ;
assign addrOut[19:16] = nTSC==1'b1 ? addrHi : 4'bz ;
assign dataBus = nWR==1'b0 ? ExDataOut : 8'bz ;

assign nAltRD = nRD ;
assign nAltWR = nWR ;

//	clock
wire SerialClock2 ;

wire iclk ;	//	Internal clock.
wire clk3 ;	//	clock enable
wire nReset1 ;
wire nReset2 ;
wire main_clk ;

// assign main_clk=gclk1 ;
 assign main_clk=clk ;

assign iclk = clk3 & main_clk ;

assign serlal_clk=clk ;

wire dclk ;

// divider2 div2(.clockIn(iclk),.nReset(nReset2),.clockOut(dclk)) ;
 assign dclk = iclk ;

FD1P3DX dff01(.CK(dclk), .D(clkQ), .Q(clkE), .CD(!nReset2), .SP(1'b1)) ;
FD1P3DX dff02(.CK(dclk), .D(!clkE), .Q(clkQ), .CD(!nReset2), .SP(1'b1)) ;

FD1P3DX dff03(.CK(main_clk), .D(1'b1), .Q(nReset1), .CD(!nReset), .SP(1'b1)) ;
FD1P3DX dff04(.CK(main_clk), .D(nReset1), .Q(nReset2), .CD(!nReset), .SP(1'b1)) ;
FD1P3DX dff05(.CK(main_clk), .D(nReset2), .Q(clk3), .CD(!nReset), .SP(1'b1)) ;

// serial clock
divider div01(.clockIn(serlal_clk), .nReset(nReset2), .clockOut(SerialClock)) ;


wire [7:0]bootROM_data ;
wire [7:0]io_data ;
wire [7:0]sramData ;

wire [7:0]net_dataSet ;


core i_core(
	.dataIn(ExDataIn),
	.clkE(clkE),
	.clkQ(clkQ),
	.nReset1(nReset1),
	.nReset2(nReset2),

	.nRD(nRD),
	.nWR(nWR),

	.dataOut(ExDataOut),
	.addrOut(addr),
	
	.nIRQ(nIRQ),
	.nTSC(nTSC & nReset2),
	.nIRQA(nIRQA),
	.IRQH(IRQH),
	
	.S(S),
	
	.sig(sig)
) ;

//	Serial port
wire [7:0]RxBuff ;
reg [7:0]TxBuff ;

wire nRDRxD ;
wire nWRTxD ;

always @(posedge nWRTxD)begin
	TxBuff <= ExDataOut ;
end

wire RxRdy ;
wire RxDclr ;
wire RxBusy ;
wire RxReset ;

wire TxRdy ;

wire [7:0]pout ;
wire rxempty ;

wire [7:0]uartStatusReg ;
assign uartStatusReg ={RxBusy, RxRdy, 1'b0, 1'b0, TxRdy, 3'b0} ;

//	serialPort I/O
wire [15:0]ioaddr ;

register16 ioaddr_reg(.D(addr), .clk(~clkQ),  .nOE(1'b0), .Q(ioaddr), .nWE(1'b0)) ;
assign nRDRxD = ioaddr[15:0]==16'h0F01 ? nRD : 1'b1 ;
assign nWRTxD = ioaddr[15:0]==16'h0F01 ? nWR : 1'b1 ;

assign nRTS = ~RxRdy ;

FD1P3DX dff06(.CK(~clkQ), .D(SerialClock), .Q(SerialClock2), .CD(~nReset), .SP(1'b1)) ;

FD1P3DX dff07(.CK(nRDRxD), .D(1'b1), .Q(RxDclr), .CD(~clkQ), .SP(1'b1)) ;

serialRxD rxd01(.dataIn(RxD), .reset(1'b1), .clk(SerialClock2),
//	.ParallelOut({pout[0],pout[1],pout[2],pout[3],pout[4],pout[5],pout[6],pout[7]}),
	.ParallelOut(pout),
	.DataRdy(RxRdy), .clr(RxDclr), .rxBusy(RxBusy), .Empty(rxempty));

//serialTxD txd01(.in({TxBuff[0],TxBuff[1],TxBuff[2],TxBuff[3],TxBuff[4],TxBuff[5],TxBuff[6],TxBuff[7]}),
//	.reset(nWRTxD), .clk(SerialClock), .serialOut(TxD), .TxRdy(TxRdy)) ;
serialTxD txd01(.in(TxBuff), .reset(nWRTxD), .clk(SerialClock2), .serialOut(TxD), .TxRdy(TxRdy)) ;

assign sig[15:8]=RxBuff ;
assign sig[40]=RxRdy ;

assign RxBuff =	pout ;

register8AC r4() ;



//	if upper 11bit eq 0 internal ROM
bootROM rom0(.Address(addr[4:0]), .Q(bootROM_data)) ;

wire sramWE ;
assign sramWE = addr[15:7]==9'b111111111 ? ~nWR : 1'b0 ;
assign nCS[1] = addr[15:7]==9'b111111111 ? 1'b0 : 1'b1 ;

assign nCS[0] = (addr[15:12]==4'b0 | addr[15:7]==9'b111111111) ? 1'b1 : 1'b0 ;

sram ram01(.Clock(~clkQ), .ClockEn(~nCS[1]), .Reset(~nReset2), .WE(sramWE), .Address(addr[6:0]),
	.Data(ExDataOut), .Q(sramData)) ;

assign ExDataIn =
	addr[15:5]==11'h000 ? bootROM_data :
//	addr[15:8]==8'h0f ? io_data :
	addr[15:0]==16'h0F00 ? uartStatusReg : 
	addr[15:0]==16'h0F01 ? RxBuff : 
	addr[15:7]==9'b111111111 ? sramData:
	dataBus ;


/*
8x16 sig monitor
*/
assign UM=
	dataBus ;
//	{SerialClock2, nRD, nRDRxD, RxDclr, rxempty, clkQ, addr[0], RxD} ;
/*
	monitor_sel==4'b0000 ? ExDataIn :	// 0
//	monitor_sel==4'b0000 ? {addr[8],addr[9],addr[10],addr[11],addr[12],addr[13],addr[14],addr[15]} :	// 0
	monitor_sel==4'b0001 ? sig[7:0] :	//	Sequencer control signal.
	monitor_sel==4'b0010 ? sig[15:8] :	//	rxbuff
//	monitor_sel==4'b0011 ? {addr[8],addr[9],addr[10],addr[11],addr[12],addr[13],addr[14],addr[15]} :	// 3
	monitor_sel==4'b0011 ? sig[23:16] :
//	monitor_sel==4'b0100 ? {addr[0],addr[1],addr[2],addr[3],addr[4],addr[5],addr[6],addr[7]} :	// 4
	monitor_sel==4'b0100 ? sig[31:24] :
	monitor_sel==4'b0101 ? sig[39:32] :	// 5 exbus
	monitor_sel==4'b0110 ? sig[47:40] :	//	assign sig[47:43] = {flag[0],flag[1],flag[2],flag[4], flga[7], jmpOpe, noJump} ;
	monitor_sel==4'b0111 ? sig[55:48] :
	monitor_sel==4'b1000 ? sig[63:56] :	// 8
//	monitor_sel==4'b1000 ? 8'h5a :

	monitor_sel==4'b1001 ? sig[71:64] :
	monitor_sel==4'b1010 ? sig[79:72] :	// A
	monitor_sel==4'b1011 ? sig[87:80] :
	monitor_sel==4'b1100 ? sig[95:88] : // UM31-
	monitor_sel==4'b1101 ? sig[103:96] :	//	CP
	monitor_sel==4'b1110 ? sig[111:104] :
//	{SerialClock, TxD, RxD, nWRTxD, nRDRxD, RxBusy, rxempty, RxRdy} ;
//	{SerialClock, nWRTxD, nRDRxD, RxBusy, rxempty, TxD, RxD, RxRdy} ;
//	{SerialClock2, nWRTxD, nRDRxD, RxBusy, rxempty, TxD, RxRdy, RxD} ;

	{SerialClock2, nRD, nRDRxD, RxDclr, rxempty, clkE, addr[0], RxD} ;
//	{SerialClock2, nRD, nRDRxD, RxDclr, rxempty, clkE, addr[0], clkQ} ;

// 	{RxRdy, rxempty, RxBusy, nRDRxD, nWRTxD, RxD, TxD, SerialClock} ;//RxDclr
	//8'b11111111 ;
*/

endmodule

/* Clock divider Main.*/
module divider2(
	input wire clockIn,
	input wire nReset,
	output wire clockOut
) ;
reg [20:0]counter ;
// assign clockOut = counter[20] ;
 assign clockOut = counter[2] ;

always @(posedge clockIn or negedge nReset)begin
	if(nReset == 1'b0)begin
		counter <= 21'b0 ;
	end
	else begin
		counter <= counter + 21'b1 ;
	end
end


endmodule

/* Clock divider */
module divider(
	input wire clockIn,
	input wire nReset,
	output wire clockOut
) ;
reg [7:0]counter ;
assign clockOut = counter[7] ;	//	7:19200 8:9600

always @(posedge clockIn or negedge nReset)begin
	if(nReset == 1'b0)begin
		counter <= 8'b0 ;
	end
	else begin
		counter <= counter + 8'b1 ;
	end
end


endmodule


/*
*/
module bankCtrl(
	input wire nWR,
	input wire [15:0]addrIn,
	input wire data,
	
	output wire [20:0] addrOut
);
reg [31:0]bank ;
wire [2:0]port ;

assign port =
	addrIn==16'h0FF1 ? 3'b001 : 
	addrIn==16'h0FF2 ? 3'b010 :
	addrIn==16'h0FF3 ? 3'b011 :
	addrIn==16'h0FF4 ? 3'b100 : 3'b000 ;
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

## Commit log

2020-01-03 Add assembler.
2020-01-04 Add schematics.
    [BROM.sch, BUS_LED.sch, CPU2908C.sch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]
2020-01-04 Add document.
    [CPU2908C.ods]
2020-01-04 Add Logisim document.
    [CPU2908C.ods]
2020-01-05 Add Schematic PDF
2020-01-07 update urom.
    [CPU2908C.ods]
2020-01-08 Update Schematic
    [FT2232D.sch, SDCARD.sch, o2_breakout.kicad_pcb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]
2020-01-08 Update PCB.
    [o2_breakout.kicad_pcb]
2020-01-18 Add schematic Rev C3.
    [BROM.sch, BUS_LED.sch, CPU2908C.sch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]
2020-01-28 Update BreakOut Schematic.
    [SDCARD.sch, o2_breakout.kicad_pcb, o2_breakout.sch]
2020-02-05 Update Schematics
    [FT2232D.sch, o2_breakout.kicad_pcb, o2_breakout.sch]
2020-02-12 Clean up PCB.
    [o2_breakout.kicad_pcb, o2_breakout.sch]
2020-02-14 Update Assembler .
2020-02-15 Clean up.
    [expr.obj]
2020-02-17 Bug Fix.
    [o2_breakout.kicad_pcb]
2020-02-21 Add .dw directive.
    [o2_breakout.kicad_pcb]
2020-02-23 asq bug fix.
    [FT2232D.sch, o2_breakout.kicad_pcb, o2_breakout.sch]
2020-02-28 PCB RevA3.
    [FT2232D.sch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]
2020-06-11 Update Gerber Data to RevA5
    [FT2232D.sch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]
2021-02-20 インストラクション変更
    [CPU2908C7.ods, CPU2908Executer.sch, FT2232D.sch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]
